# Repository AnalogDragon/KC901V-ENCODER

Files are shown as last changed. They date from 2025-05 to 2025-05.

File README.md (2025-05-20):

# KC901V-ENCODER

KC901V顶部的编码器手感十分屎，猜测它设计时仅采用了单边缘计数，另一个边只做了电平判断方向。所以在慢速左右转或者偶然回弹的时候，会有不自然的光标移动。

所以做了一个支持双边缘的编码器模块替换原装的编码器小板子，先让我嚼一遍编码器数据再喂给主板，优化手感与体验。

包含了硬件与软件。  
应该可以用于其他配置的相同外观的KC901x，新版的大约已经修复了相关的问题。

##  

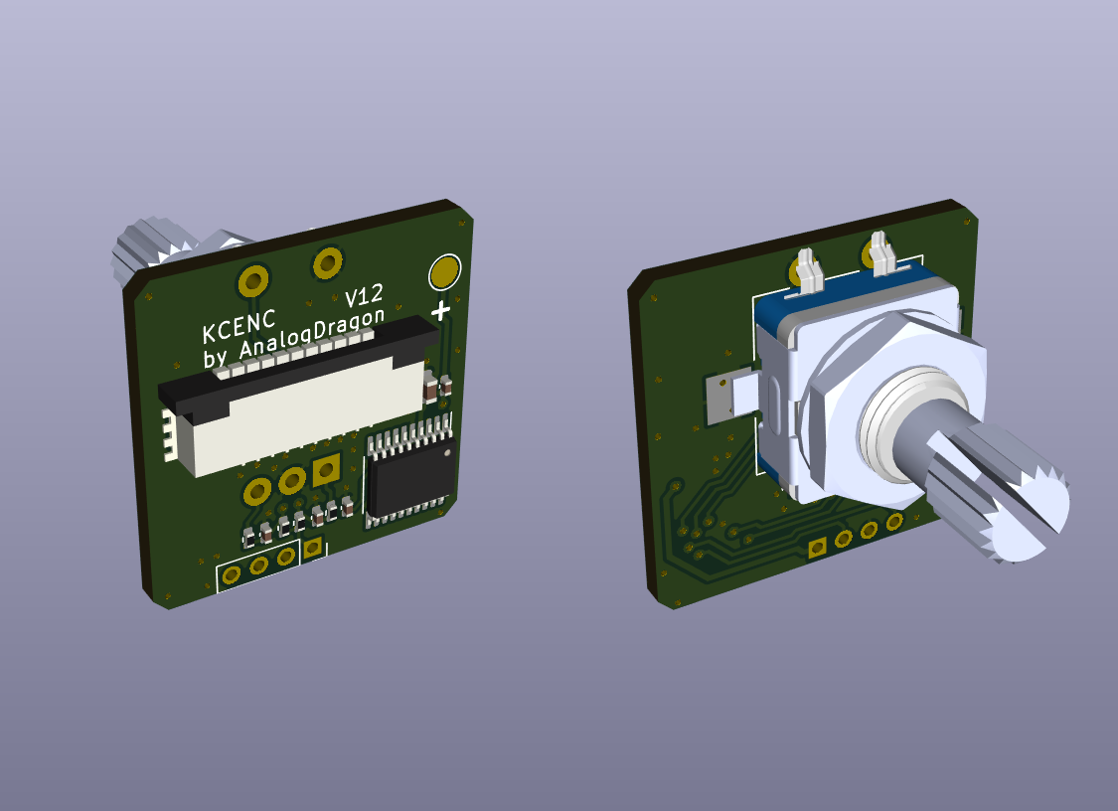
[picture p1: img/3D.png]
  

与原小板比较
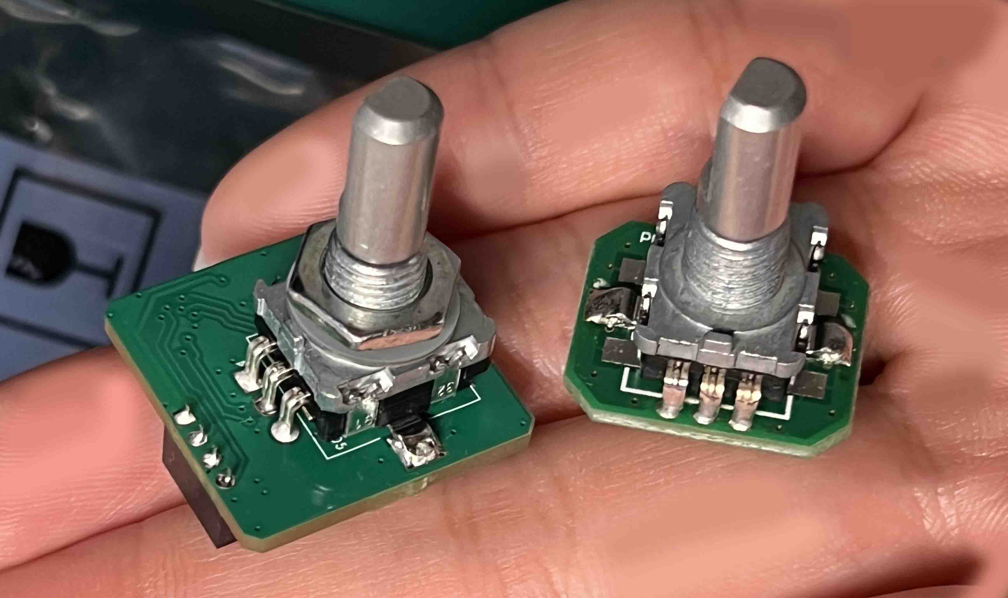
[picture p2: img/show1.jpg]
  
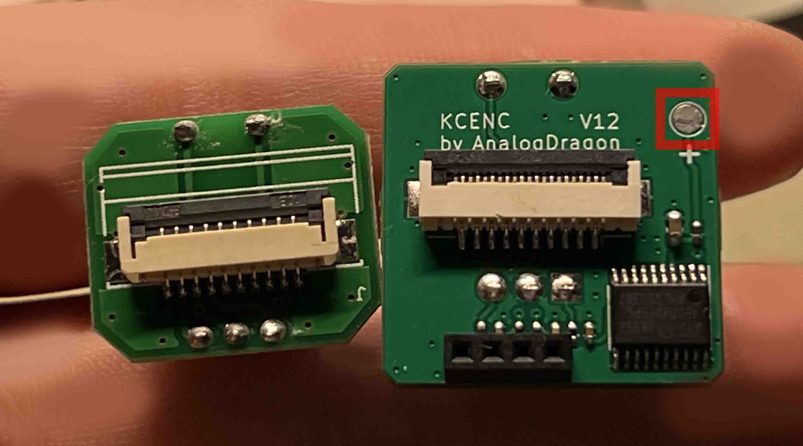
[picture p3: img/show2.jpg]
  

## 安装

替换原编码器位置，但是因为需要额外的3.3V供电，所以还需要一根飞线将主板的3.3V引上来。

这里使用了一根空中连接的1p杜邦线连接。

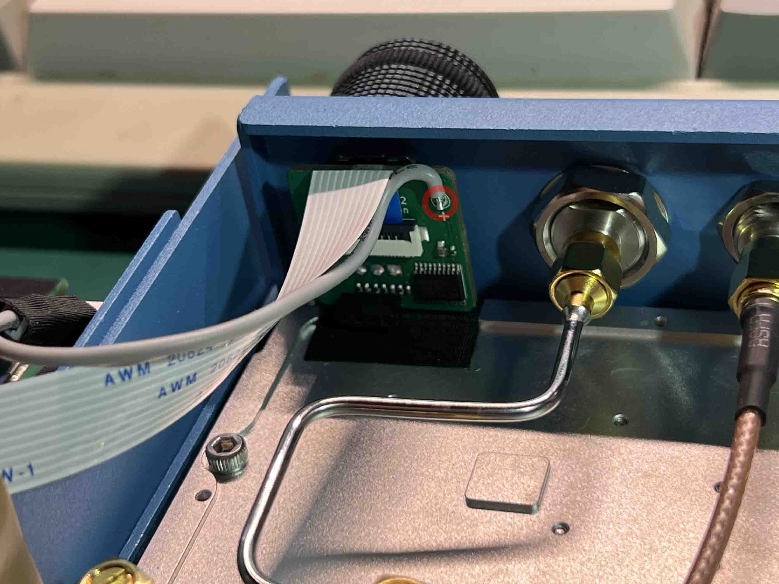
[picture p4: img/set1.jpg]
  
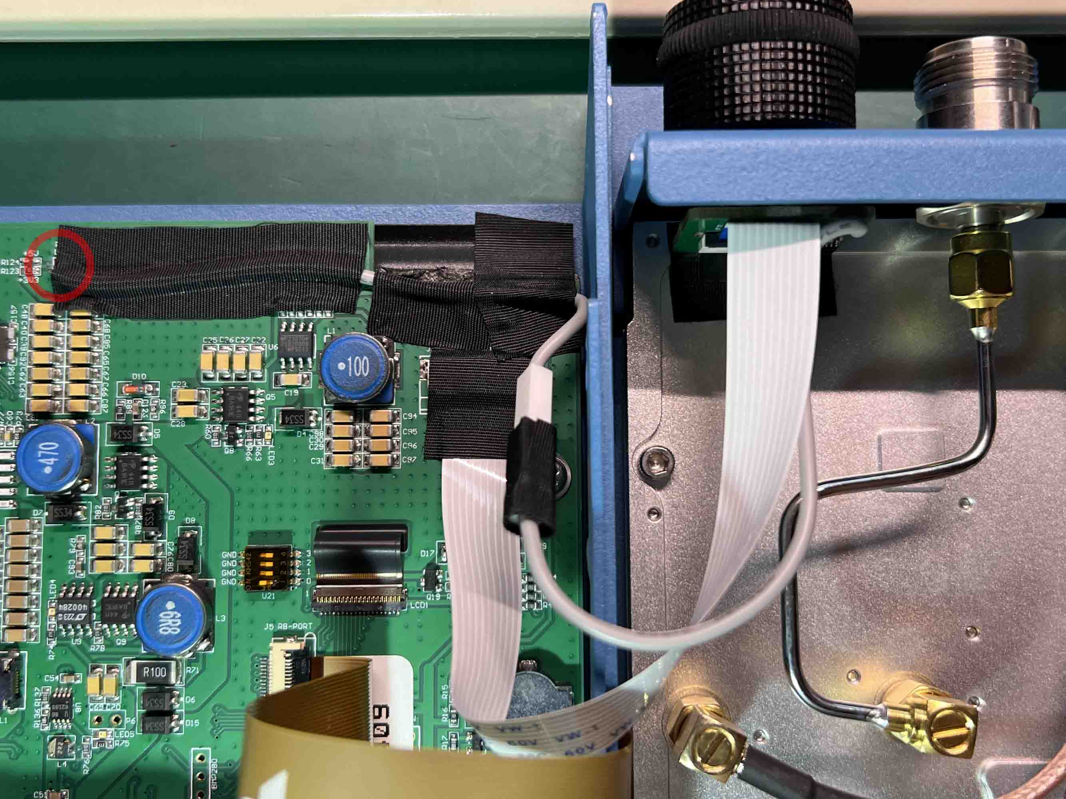
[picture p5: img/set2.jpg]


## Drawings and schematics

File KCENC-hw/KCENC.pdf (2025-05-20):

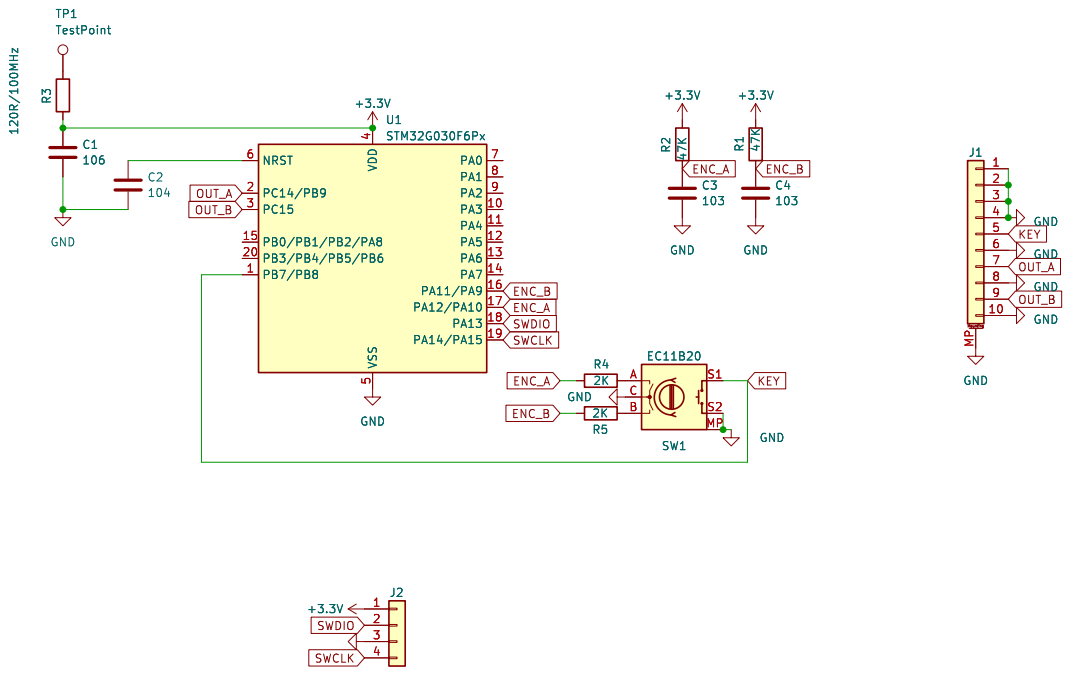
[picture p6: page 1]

5 NRST 6 PA0 7 PA1 8 PA2 9 U1STM32G030F6Px GND GND GND GND

Id: 1/1 Title: File: KCENC.kicad_sch Sheet: /

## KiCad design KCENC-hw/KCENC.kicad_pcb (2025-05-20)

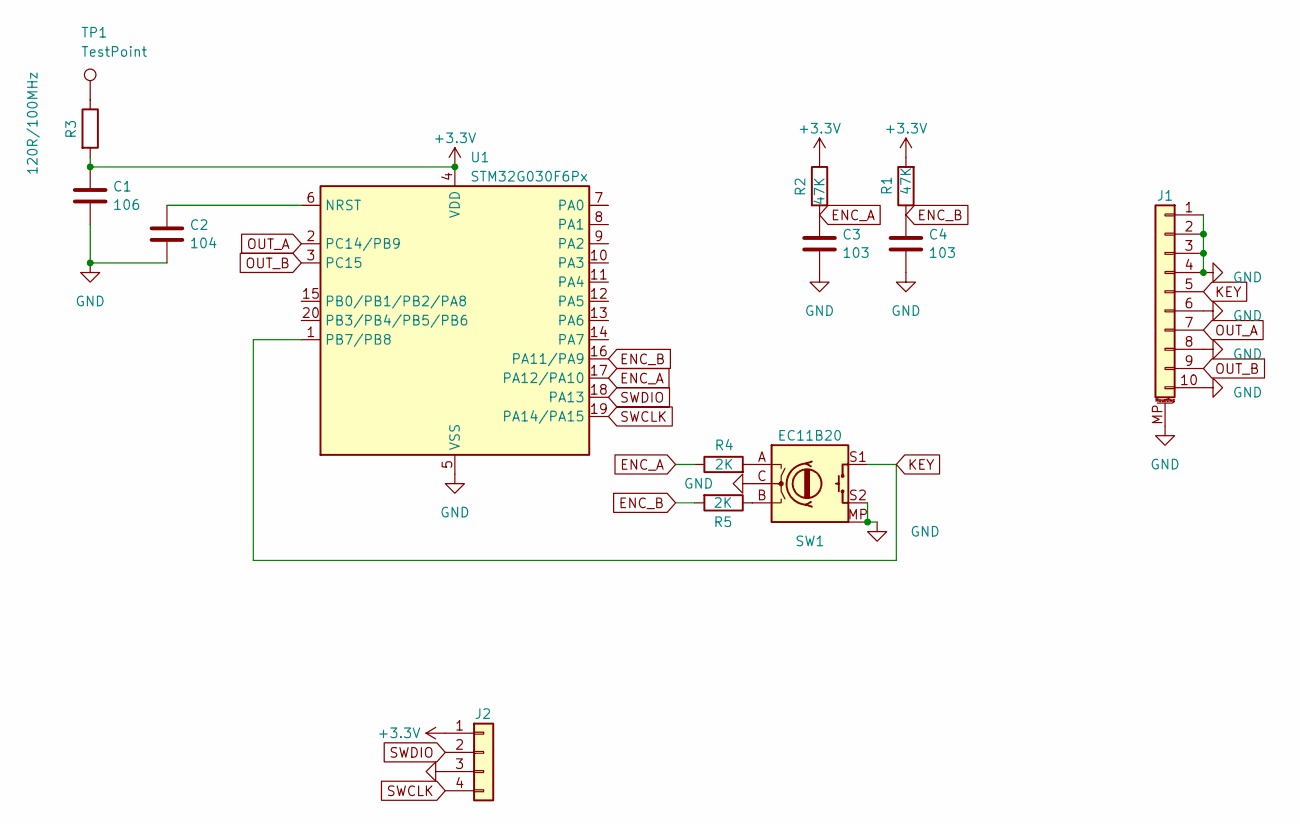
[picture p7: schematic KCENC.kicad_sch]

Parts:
C1: 106; C_0603_1608Metric
C2: 104; C_0402_1005Metric
C3, C4: 103; C_0402_1005Metric
J1: Conn_01x10_MountingPin; Molex_200528-0100_1x10-1MP_P1.00mm_Horizontal
J2: Conn_01x04; PinSocket_1x04_P2.00mm_Vertical
R1, R2: 47K; R_0402_1005Metric
R3: 120R/100MHz; C_0402_1005Metric
R4, R5: 2K; R_0402_1005Metric
SW1: EC11B20; RotaryEncoder_Alps_EC11E-Switch_Vertical_H20mm
TP1: TestPoint; TestPoint_Pad_D2.0mm
U1: STM32G030F6Px; TSSOP-20_4.4x6.5mm_P0.65mm

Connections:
+3.3V: C1.1, J2.1, R1.2, R2.1, R3.2, U1.4 (VDD)
ENC_A: C3.1, R2.2, R4.1, U1.17 (PA12/PA10)
ENC_B: C4.1, R1.1, R5.2, U1.16 (PA11/PA9)
GND: C1.2, C2.2, C3.2, C4.2, J1.1, J1.2, J1.3, J1.4, J1.6, J1.8, J1.10, J1.MP (MountPin), J2.3, SW1.C, SW1.MP, SW1.S2, U1.5 (VSS)
KEY: J1.5, SW1.S1, U1.1 (PB7/PB8)
unnamed: R3.1, TP1.1
unnamed: R4.2, SW1.A
unnamed: R5.1, SW1.B
unnamed: C2.1, U1.6 (NRST)
OUT_A: J1.7, U1.2 (PC14/PB9)
OUT_B: J1.9, U1.3 (PC15)
SWCLK: J2.4, U1.19 (PA14/PA15)
SWDIO: J2.2, U1.18 (PA13)

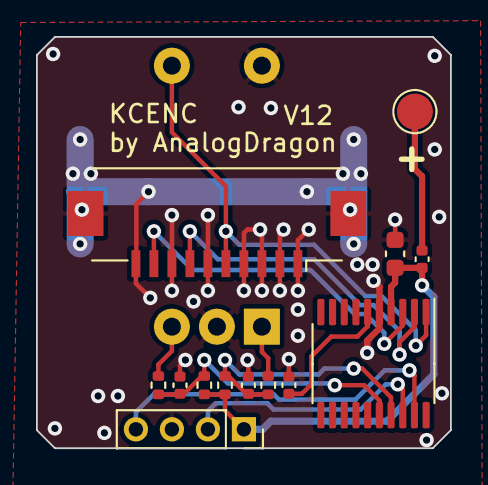
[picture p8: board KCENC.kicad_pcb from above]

Board: 2 copper layers, 23.0 x 22.9 mm, 14 parts (1 on the bottom side), 13 nets.

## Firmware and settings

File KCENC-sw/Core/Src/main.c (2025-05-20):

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
/* Includes ------------------------------------------------------------------*/
#include "main.h"

 IWDG_HandleTypeDef hiwdg;

void SystemClock_Config(void);
static void MX_GPIO_Init(void);
static void MX_IWDG_Init(void);
/* USER CODE BEGIN 0 */

volatile int16_t input_enc_count;
int16_t input_enc_count_temp;
int16_t input_enc_count_bak;


volatile int16_t enc_count = 0;
volatile uint8_t output_enc_step = 0;
volatile int8_t output_enc_count = 0;

void enc_out_task(void){
	
	if(enc_count > 10)enc_count = 10;
	if(enc_count < -10)enc_count = -10;
	
	if(output_enc_step > 3)output_enc_step = 0;
	
	//output step
	if(output_enc_count != 0 && output_enc_count < 3 && output_enc_count > -3){
		if(output_enc_count > 0){
			output_enc_count--;
			if(output_enc_step < 3)
				output_enc_step++;
			else
				output_enc_step = 0;
		}
		else{
			output_enc_count++;
			if(output_enc_step == 0)
				output_enc_step = 3;
			else
				output_enc_step--;
		}
		
		switch(output_enc_step){
			case 0:
				OUT_A_GPIO_Port->BRR = OUT_A_Pin;	//0
				OUT_B_GPIO_Port->BRR = OUT_B_Pin;	//0
				break;
			case 1:
				OUT_A_GPIO_Port->BRR = OUT_A_Pin;	//0
				OUT_B_GPIO_Port->BSRR = OUT_B_Pin;	//1
				break;
			case 2:
				OUT_A_GPIO_Port->BSRR = OUT_A_Pin;	//1
				OUT_B_GPIO_Port->BSRR = OUT_B_Pin;	//1
				break;
			case 3:
				OUT_A_GPIO_Port->BSRR = OUT_A_Pin;	//1
				OUT_B_GPIO_Port->BRR = OUT_B_Pin;	//0
				break;
		}
		
		return;
	}
	
	
	if(enc_count > 0){
		enc_count--;
		output_enc_count = 2;
	}
	else if(enc_count < 0){
		enc_count++;
		output_enc_count = -2;
	}
	
}


/* USER CODE END 0 */

/**
  * @brief  The application entry point.
  * @retval int
  */
int main(void)
{
  /* MCU Configuration--------------------------------------------------------*/

  /* Reset of all peripherals, Initializes the Flash interface and the Systick. */
  HAL_Init();

  /* Configure the system clock */
  SystemClock_Config();

  /* Initialize all configured peripherals */
  MX_GPIO_Init();
  MX_IWDG_Init();
  /* Infinite loop */
  /* USER CODE BEGIN WHILE */
  while (1)
  {
		HAL_IWDG_Refresh(&hiwdg);
//		input_enc_count_temp  = input_enc_count/2;
//		if(input_enc_count_bak != input_enc_count_temp){
//			enc_count += input_enc_count_temp - input_enc_count_bak;
//			input_enc_count_bak += input_enc_count_temp - input_enc_count_bak;
//		}
		if((input_enc_count - 2) >= input_enc_count_bak){
			enc_count--;
			input_enc_count_bak += 2;
		}
		else if((input_enc_count + 2) <= input_enc_count_bak){
			enc_count++;
			input_enc_count_bak -= 2;
		}
		enc_out_task();
		HAL_Delay(1);
    /* USER CODE END WHILE */

    /* USER CODE BEGIN 3 */
  }
  /* USER CODE END 3 */
}

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


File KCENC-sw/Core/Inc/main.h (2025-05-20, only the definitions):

#define KEY_Pin GPIO_PIN_7
#define KEY_GPIO_Port GPIOB
#define OUT_A_Pin GPIO_PIN_14
#define OUT_A_GPIO_Port GPIOC
#define OUT_B_Pin GPIO_PIN_15
#define OUT_B_GPIO_Port GPIOC
#define ENC_B_Pin GPIO_PIN_11
#define ENC_B_GPIO_Port GPIOA
#define ENC_B_EXTI_IRQn EXTI4_15_IRQn
#define ENC_A_Pin GPIO_PIN_12
#define ENC_A_GPIO_Port GPIOA
#define ENC_A_EXTI_IRQn EXTI4_15_IRQn

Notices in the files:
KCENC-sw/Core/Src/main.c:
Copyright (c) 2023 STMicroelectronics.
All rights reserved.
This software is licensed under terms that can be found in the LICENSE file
